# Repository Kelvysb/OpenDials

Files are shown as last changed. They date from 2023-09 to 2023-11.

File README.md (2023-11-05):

# OpenDials
Open Dials - Open Source Gamepad 

[Color Roll Test Game](https://github.com/Kelvysb/ColorRoll)

Version video:

https://www.youtube.com/watch?v=tNQyPmjfuhA&t=68s&ab_channel=CiaNCIStudio

V1 3d: models (printables)

https://www.thingiverse.com/thing:6273114

https://skfb.ly/oMzWV

Ingredients:
1 - Arduino Pro micro
7 - push buttons
2 - rotary encoders
2 - leds
1 - 1k resistor
A lot - Wires
4 - M3 - bolts and nuts

Circuit:

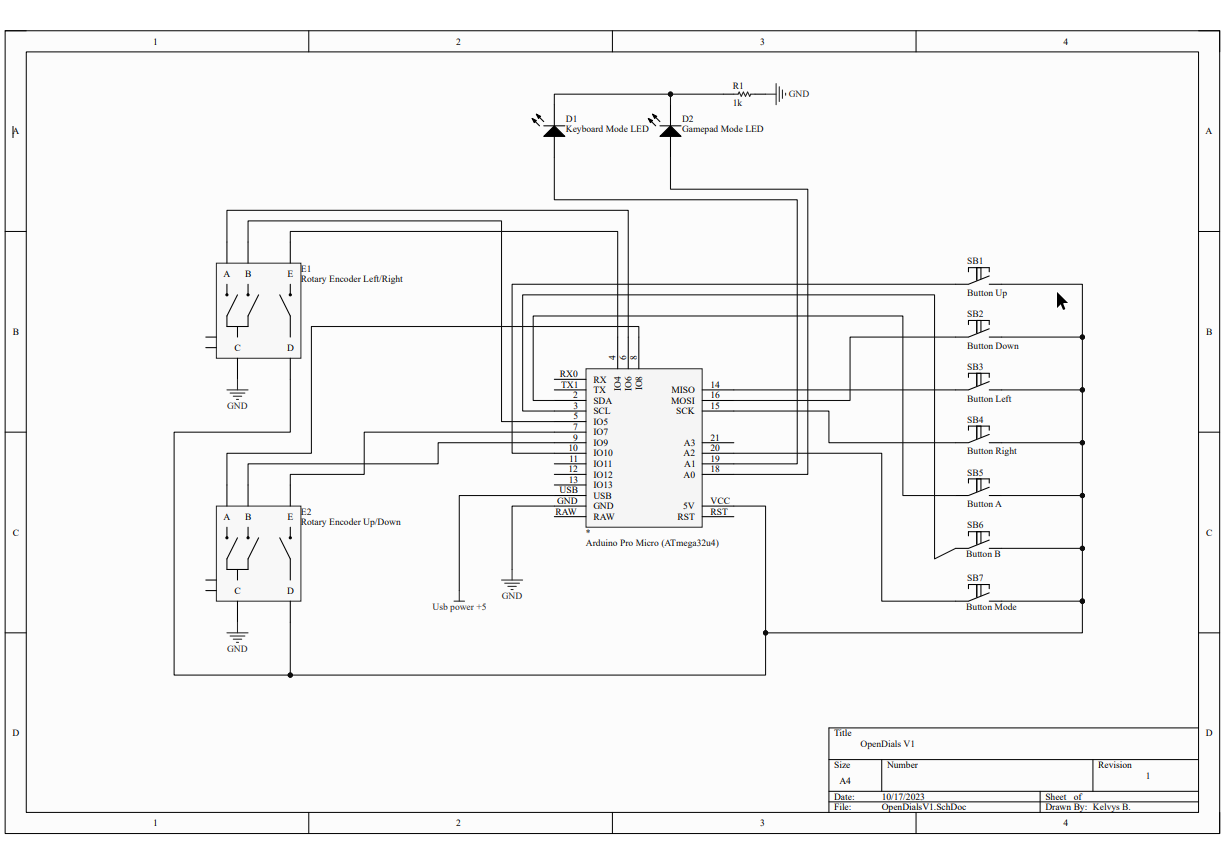
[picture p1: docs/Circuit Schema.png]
circuit


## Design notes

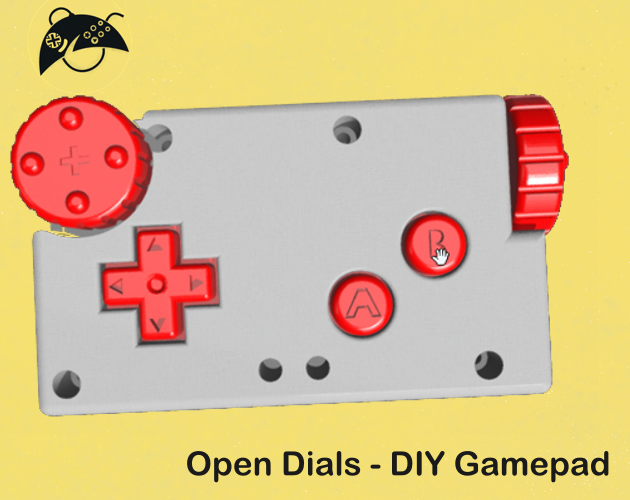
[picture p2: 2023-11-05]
docs/Cover.png

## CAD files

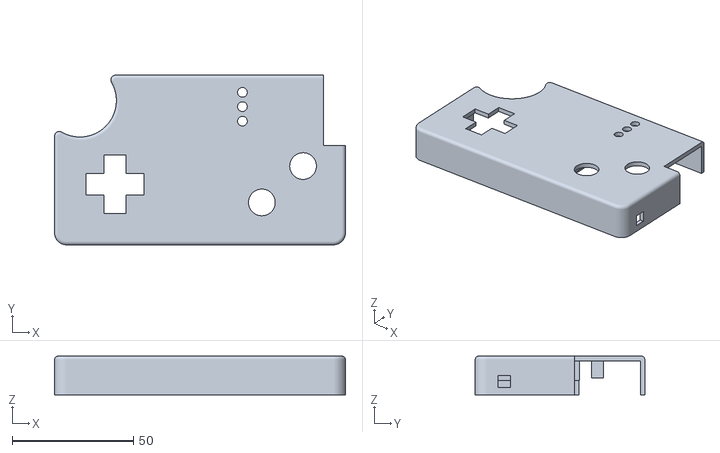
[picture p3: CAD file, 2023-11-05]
Hardware/Printing/V3/OpenDials_v3-Top.stl
120.0 x 70.0 x 16.0

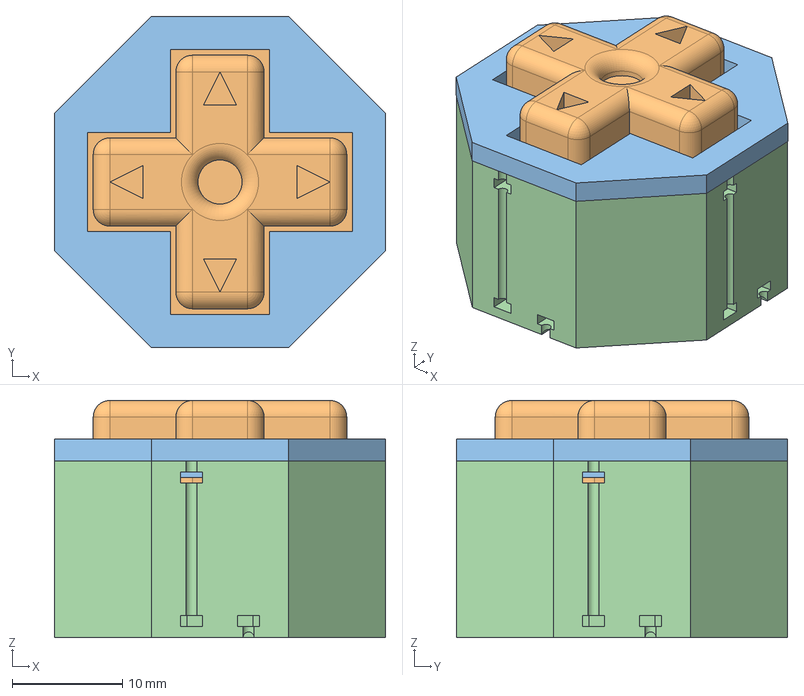
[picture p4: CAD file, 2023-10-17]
Hardware/Source/OpenDials_v2/OpenDials_v2.FCStd
30.0 x 30.0 x 21.5 mm
DPadDisc
DPadButtons
DPadTop
DPadBody

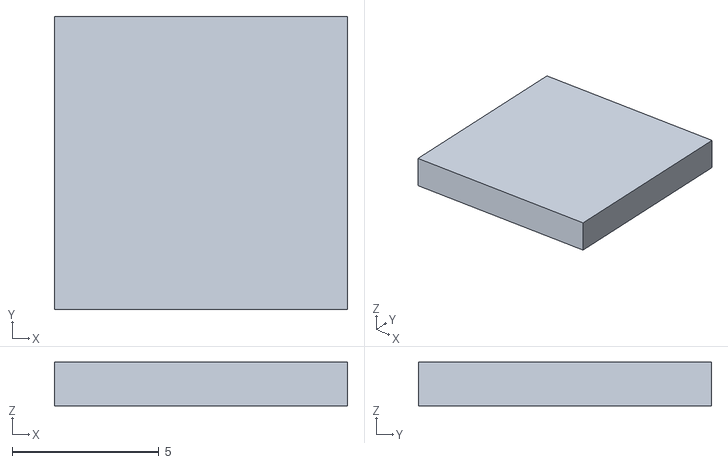
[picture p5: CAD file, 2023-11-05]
Hardware/Printing/V3/OpenDials_v3-ButtonsPlate.stl
10.0 x 10.0 x 1.50

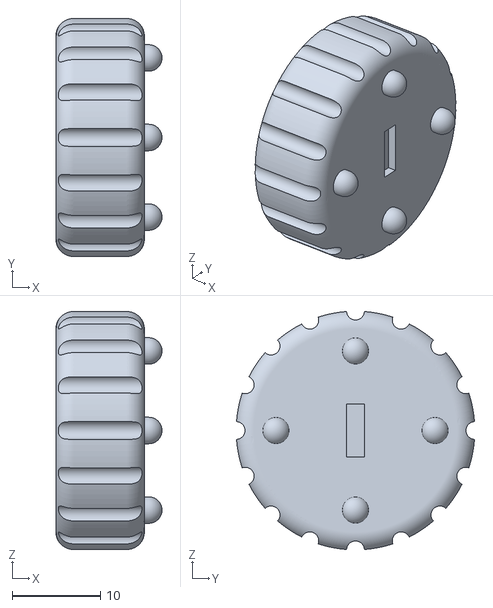
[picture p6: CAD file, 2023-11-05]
Hardware/Printing/V3/OpenDials_v3-DialUD.stl
12.0 x 26.9 x 26.9

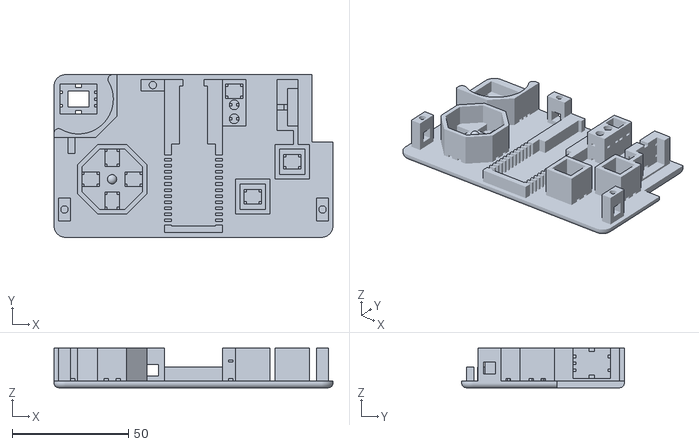
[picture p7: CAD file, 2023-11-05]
Hardware/Printing/V3/OpenDials_v3-Bottom.stl
120.0 x 70.0 x 17.0

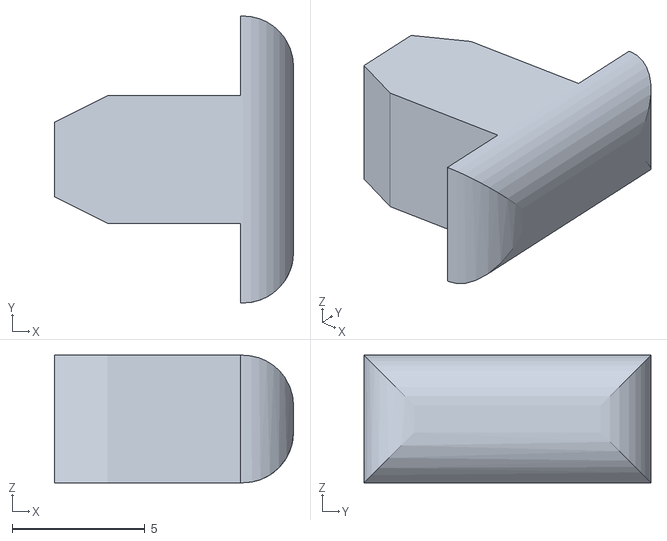
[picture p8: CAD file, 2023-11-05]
Hardware/Printing/V3/OpenDials_v3-ClosingPin.stl
9.00 x 10.8 x 4.80

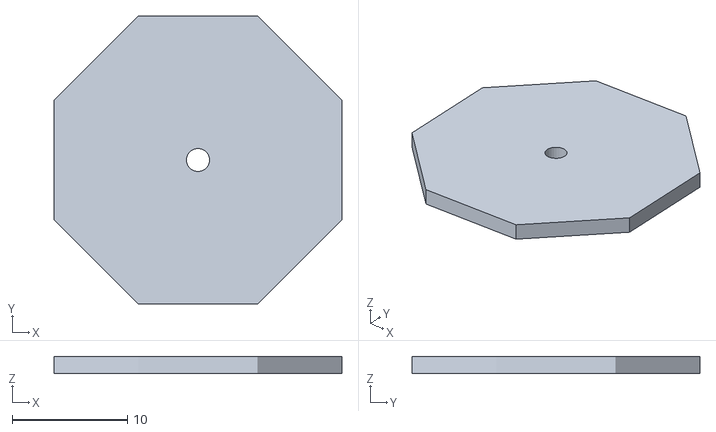
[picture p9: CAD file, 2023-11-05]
Hardware/Printing/V3/OpenDials_v3-DPadDisc.stl
24.9 x 24.9 x 1.50

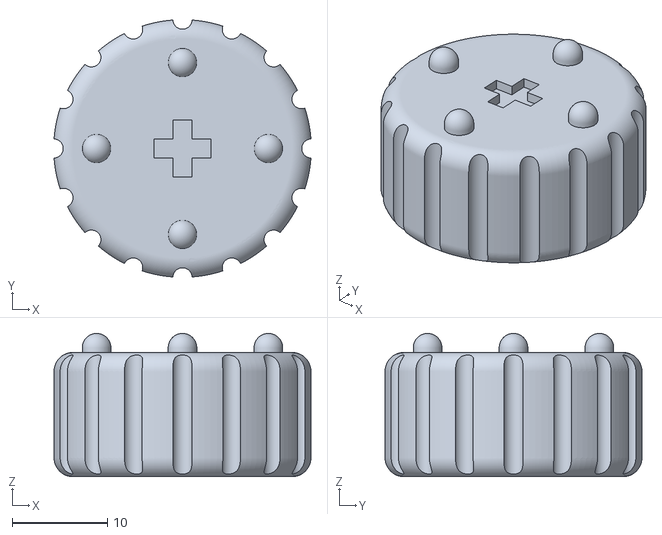
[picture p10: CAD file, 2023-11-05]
Hardware/Printing/V3/OpenDials_v3-RLDial.stl
26.9 x 26.9 x 15.0

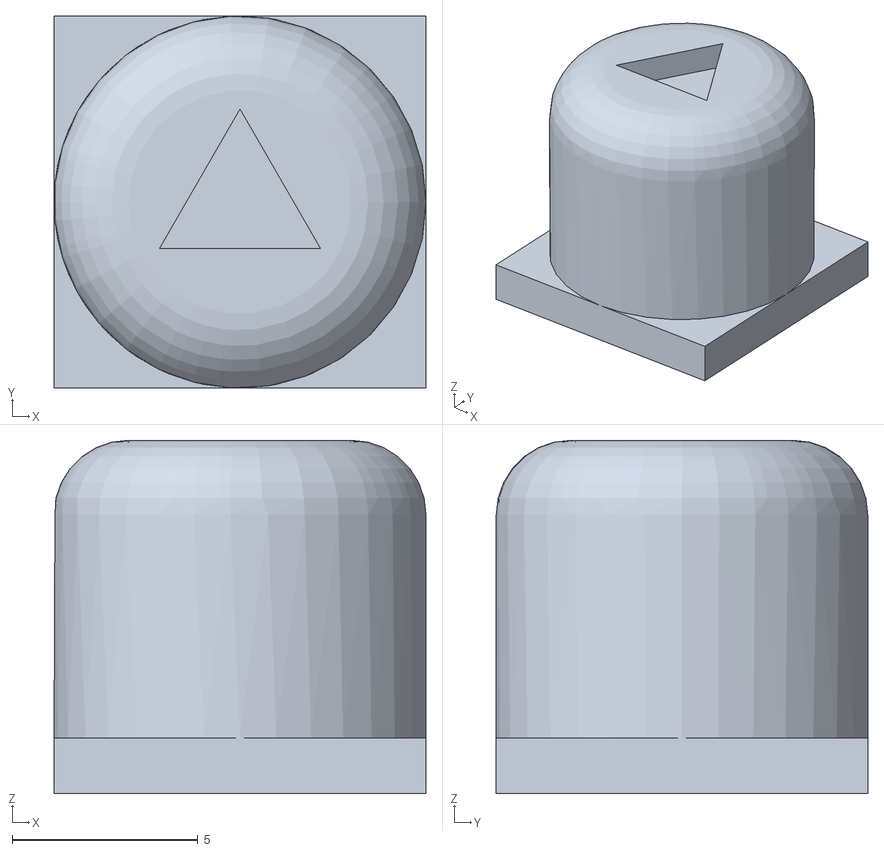
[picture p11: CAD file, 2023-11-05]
Hardware/Printing/V3/OpenDials_v3-ButtonA.stl
10.0 x 10.0 x 9.50

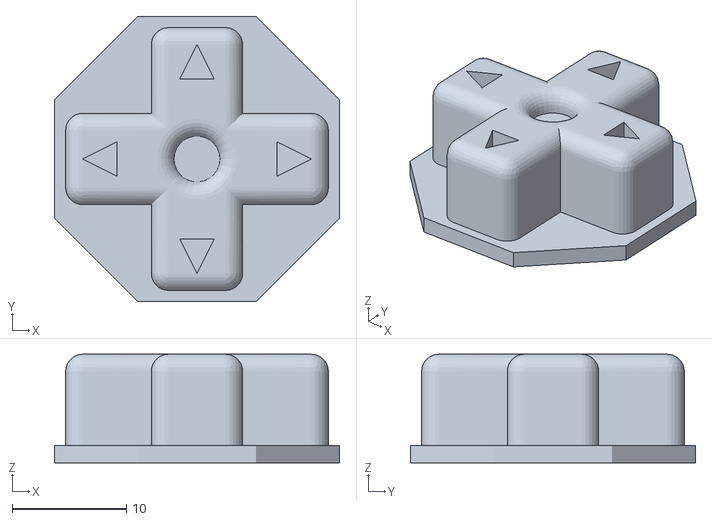
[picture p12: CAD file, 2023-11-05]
Hardware/Printing/V3/OpenDials_v3-DPadButtons.stl
24.9 x 24.9 x 9.50

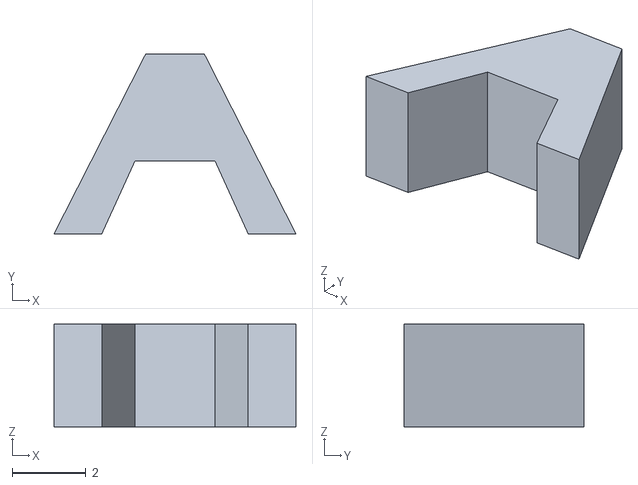
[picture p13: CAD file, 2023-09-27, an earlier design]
Hardware/Printing/V1/OpenDials-ButtonsDetailA.stl
6.58 x 4.89 x 2.80

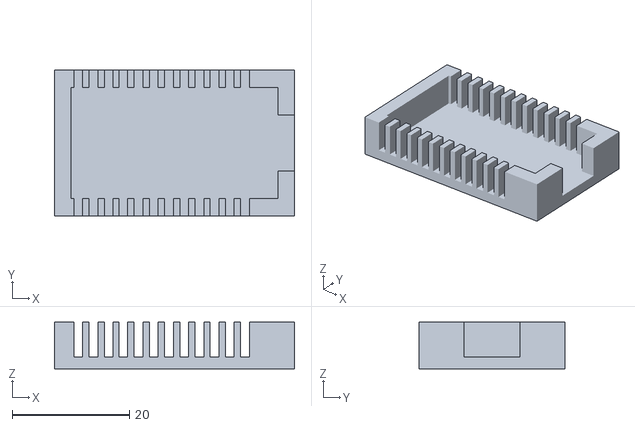
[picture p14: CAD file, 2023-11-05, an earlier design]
Hardware/Printing/V2/ArduinoSlot/ArduinoSlotBody.stl
41.0 x 25.0 x 8.00

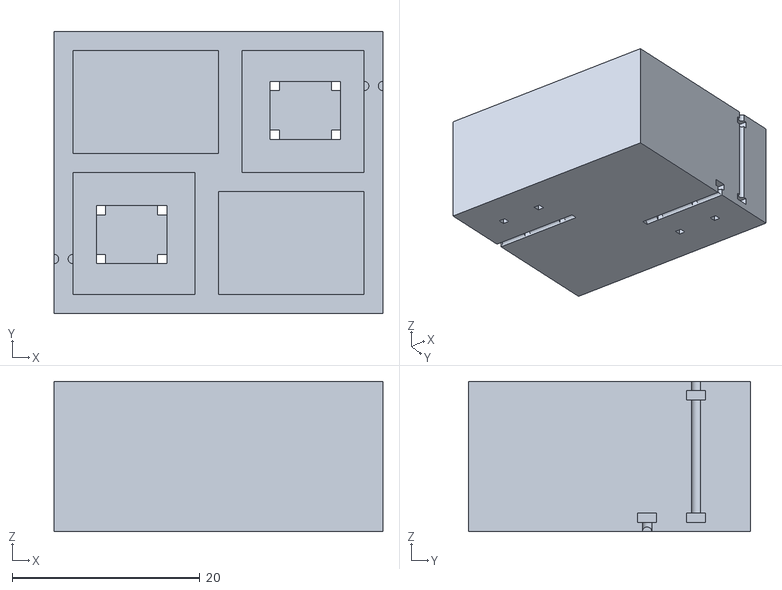
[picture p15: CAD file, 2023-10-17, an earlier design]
Hardware/Printing/V2/Buttons/OpenDials_v2-ButtonsBody.stl
35.0 x 30.0 x 16.0

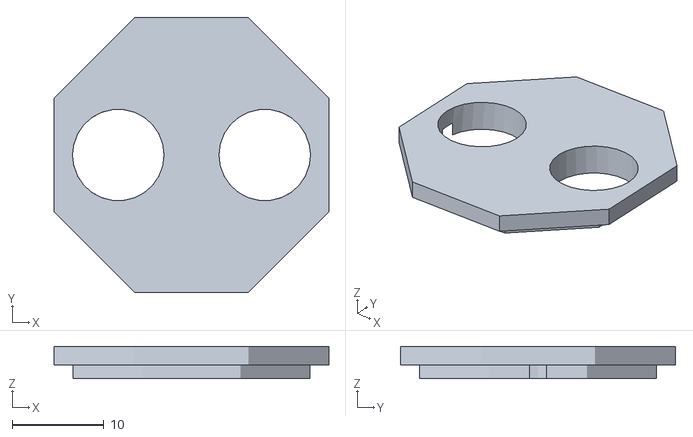
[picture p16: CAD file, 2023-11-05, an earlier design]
Hardware/Printing/V2/ButtonsOct/ButtonsOctTop.stl
30.0 x 30.0 x 3.50

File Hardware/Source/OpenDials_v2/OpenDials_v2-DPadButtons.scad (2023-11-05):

// CSG file generated from FreeCAD 0.21.1
group() {
 group(){
polyhedron ( points = [[3.500000,0.000000,21.500000],[-2.500000,-2.500000,21.500000],[-10.000000,-2.500000,21.500000],[-10.000000,0.000000,21.500000],[-10.000000,2.500000,21.500000],[-2.500000,2.500000,21.500000],[-2.500000,10.000000,21.500000],[0.000000,10.000000,21.500000],[2.500000,10.000000,21.500000],[2.500000,2.500000,21.500000],[10.000000,2.500000,21.500000],[10.000000,0.000000,21.500000],[10.000000,-2.500000,21.500000],[2.500000,-2.500000,21.500000],[2.500000,-10.000000,21.500000],[-0.000000,-10.000000,21.500000],[-2.500000,-10.000000,21.500000],[7.000000,-1.500000,21.500000],[7.000000,1.500000,21.500000],[-1.500000,-7.000000,21.500000],[1.500000,-7.000000,21.500000],[1.500000,7.000000,21.500000],[-1.500000,7.000000,21.500000],[-7.000000,1.500000,21.500000],[-7.000000,-1.500000,21.500000],[2.000000,0.000000,20.000000],[-4.000000,-4.000000,20.000000],[-10.000000,-4.000000,20.000000],[-11.500000,-2.500000,20.000000],[-11.500000,2.500000,20.000000],[-10.000000,4.000000,20.000000],[-4.000000,4.000000,20.000000],[-4.000000,10.000000,20.000000],[-2.500000,11.500000,20.000000],[2.500000,11.500000,20.000000],[4.000000,10.000000,20.000000],[4.000000,4.000000,20.000000],[10.000000,4.000000,20.000000],[11.500000,2.500000,20.000000],[11.500000,-2.500000,20.000000],[10.000000,-4.000000,20.000000],[4.000000,-4.000000,20.000000],[4.000000,-10.000000,20.000000],[2.500000,-11.500000,20.000000],[-2.500000,-11.500000,20.000000],[-4.000000,-10.000000,20.000000],[7.000000,-1.500000,19.500000],[10.000000,0.000000,19.500000],[7.000000,1.500000,19.500000],[-1.500000,-7.000000,19.500000],[-0.000000,-10.000000,19.500000],[1.500000,-7.000000,19.500000],[1.500000,7.000000,19.500000],[0.000000,10.000000,19.500000],[-1.500000,7.000000,19.500000],[-7.000000,1.500000,19.500000],[-10.000000,0.000000,19.500000],[-7.000000,-1.500000,19.500000],[2.000000,0.000000,19.500000],[-4.000000,-4.000000,13.500000],[-10.000000,-4.000000,13.500000],[-11.500000,-2.500000,13.500000],[-11.500000,2.500000,13.500000],[-4.000000,4.000000,13.500000],[-10.000000,4.000000,13.500000],[-4.000000,10.000000,13.500000],[-2.500000,11.500000,13.500000],[2.500000,11.500000,13.500000],[4.000000,4.000000,13.500000],[4.000000,10.000000,13.500000],[10.000000,4.000000,13.500000],[11.500000,2.500000,13.500000],[11.500000,-2.500000,13.500000],[4.000000,-4.000000,13.500000],[10.000000,-4.000000,13.500000],[4.000000,-10.000000,13.500000],[2.500000,-11.500000,13.500000],[-2.500000,-11.500000,13.500000],[-4.000000,-10.000000,13.500000],[5.166226,-12.472374,13.500000],[12.472374,-5.166226,13.500000],[12.472374,5.166226,13.500000],[5.166226,12.472374,13.500000],[-5.166226,12.472374,13.500000],[-12.472374,5.166226,13.500000],[-12.472374,-5.166226,13.500000],[-5.166226,-12.472374,13.500000],[5.166226,-12.472374,12.000000],[12.472374,-5.166226,12.000000],[12.472374,5.166226,12.000000],[5.166226,12.472374,12.000000],[-5.166226,12.472374,12.000000],[-12.472374,5.166226,12.000000],[-12.472374,-5.166226,12.000000],[-5.166226,-12.472374,12.000000],[3.197409,1.423578,21.500000],[2.341957,2.601007,21.500000],[1.081560,3.328698,21.500000],[-0.365850,3.480827,21.500000],[-1.750000,3.031089,21.500000],[-2.831559,2.057248,21.500000],[-3.423517,0.727691,21.500000],[-3.423517,-0.727691,21.500000],[-2.831559,-2.057248,21.500000],[-1.750000,-3.031089,21.500000],[-0.365850,-3.480827,21.500000],[1.081560,-3.328698,21.500000],[2.341957,-2.601007,21.500000],[3.197409,-1.423578,21.500000],[-3.750000,-2.500000,21.500000],[-5.000000,-2.500000,21.500000],[-6.250000,-2.500000,21.500000],[-7.500000,-2.500000,21.500000],[-8.750000,-2.500000,21.500000],[-10.000000,-1.666667,21.500000],[-10.000000,-0.833333,21.500000],[-10.000000,0.833333,21.500000],[-10.000000,1.666667,21.500000],[-8.750000,2.500000,21.500000],[-7.500000,2.500000,21.500000],[-6.250000,2.500000,21.500000],[-5.000000,2.500000,21.500000],[-3.750000,2.500000,21.500000],[-2.500000,3.750000,21.500000],[-2.500000,5.000000,21.500000],[-2.500000,6.250000,21.500000],[-2.500000,7.500000,21.500000],[-2.500000,8.750000,21.500000],[-1.666667,10.000000,21.500000],[-0.833333,10.000000,21.500000],[0.833333,10.000000,21.500000],[1.666667,10.000000,21.500000],[2.500000,8.750000,21.500000],[2.500000,7.500000,21.500000],[2.500000,6.250000,21.500000],[2.500000,5.000000,21.500000],[2.500000,3.750000,21.500000],[3.750000,2.500000,21.500000],[5.000000,2.500000,21.500000],[6.250000,2.500000,21.500000],[7.500000,2.500000,21.500000],[8.750000,2.500000,21.500000],[10.000000,1.666667,21.500000],[10.000000,0.833333,21.500000],[10.000000,-0.833333,21.500000],[10.000000,-1.666667,21.500000],[8.750000,-2.500000,21.500000],[7.500000,-2.500000,21.500000],[6.250000,-2.500000,21.500000],[5.000000,-2.500000,21.500000],[3.750000,-2.500000,21.500000],[2.500000,-3.750000,21.500000],[2.500000,-5.000000,21.500000],[2.500000,-6.250000,21.500000],[2.500000,-7.500000,21.500000],[2.500000,-8.750000,21.500000],[1.666667,-10.000000,21.500000],[0.833333,-10.000000,21.500000],[-0.833333,-10.000000,21.500000],[-1.666667,-10.000000,21.500000],[-2.500000,-8.750000,21.500000],[-2.500000,-7.500000,21.500000],[-2.500000,-6.250000,21.500000],[-2.500000,-5.000000,21.500000],[-2.500000,-3.750000,21.500000],[7.750000,-1.125000,21.500000],[8.500000,-0.750000,21.500000],[9.250000,-0.375000,21.500000],[9.250000,0.375000,21.500000],[8.500000,0.750000,21.500000],[7.750000,1.125000,21.500000],[7.000000,0.750000,21.500000],[7.000000,0.000000,21.500000],[7.000000,-0.750000,21.500000],[-1.125000,-7.750000,21.500000],[-0.750000,-8.500000,21.500000],[-0.375000,-9.250000,21.500000],[0.375000,-9.250000,21.500000],[0.750000,-8.500000,21.500000],[1.125000,-7.750000,21.500000],[0.750000,-7.000000,21.500000],[-0.000000,-7.000000,21.500000],[-0.750000,-7.000000,21.500000],[1.125000,7.750000,21.500000],[0.750000,8.500000,21.500000],[0.375000,9.250000,21.500000],[-0.375000,9.250000,21.500000],[-0.750000,8.500000,21.500000],[-1.125000,7.750000,21.500000],[-0.750000,7.000000,21.500000],[0.000000,7.000000,21.500000],[0.750000,7.000000,21.500000],[-7.750000,1.125000,21.500000],[-8.500000,0.750000,21.500000],[-9.250000,0.375000,21.500000],[-9.250000,-0.375000,21.500000],[-8.500000,-0.750000,21.500000],[-7.750000,-1.125000,21.500000],[-7.000000,-0.750000,21.500000],[-7.000000,0.000000,21.500000],[-7.000000,0.750000,21.500000],[2.750000,0.000000,21.299038],[2.200962,0.000000,20.750000],[1.532089,1.285575,20.000000],[0.347296,1.969615,20.000000],[-1.000000,1.732051,20.000000],[-1.879385,0.684040,20.000000],[-1.879385,-0.684040,20.000000],[-1.000000,-1.732051,20.000000],[0.347296,-1.969615,20.000000],[1.532089,-1.285575,20.000000],[-3.734545,-3.734545,20.851995],[-3.163246,-3.163246,21.345402],[-10.000000,-3.250000,21.299038],[-10.000000,-3.799038,20.750000],[-5.200000,-4.000000,20.000000],[-6.400000,-4.000000,20.000000],[-7.600000,-4.000000,20.000000],[-8.800000,-4.000000,20.000000],[-10.750000,-2.500000,21.299038],[-11.299038,-2.500000,20.750000],[-10.750000,2.500000,21.299038],[-11.299038,2.500000,20.750000],[-11.500000,-1.500000,20.000000],[-11.500000,-0.500000,20.000000],[-11.500000,0.500000,20.000000],[-11.500000,1.500000,20.000000],[-10.000000,3.250000,21.299038],[-10.000000,3.799038,20.750000],[-3.734545,3.734545,20.851995],[-3.163246,3.163246,21.345402],[-8.800000,4.000000,20.000000],[-7.600000,4.000000,20.000000],[-6.400000,4.000000,20.000000],[-5.200000,4.000000,20.000000],[-3.250000,10.000000,21.299038],[-3.799038,10.000000,20.750000],[-4.000000,5.200000,20.000000],[-4.000000,6.400000,20.000000],[-4.000000,7.600000,20.000000],[-4.000000,8.800000,20.000000],[-2.500000,10.750000,21.299038],[-2.500000,11.299038,20.750000],[2.500000,10.750000,21.299038],[2.500000,11.299038,20.750000],[-1.500000,11.500000,20.000000],[-0.500000,11.500000,20.000000],[0.500000,11.500000,20.000000],[1.500000,11.500000,20.000000],[3.250000,10.000000,21.299038],[3.799038,10.000000,20.750000],[3.734545,3.734545,20.851995],[3.163246,3.163246,21.345402],[4.000000,8.800000,20.000000],[4.000000,7.600000,20.000000],[4.000000,6.400000,20.000000],[4.000000,5.200000,20.000000],[10.000000,3.250000,21.299038],[10.000000,3.799038,20.750000],[5.200000,4.000000,20.000000],[6.400000,4.000000,20.000000],[7.600000,4.000000,20.000000],[8.800000,4.000000,20.000000],[10.750000,2.500000,21.299038],[11.299038,2.500000,20.750000],[10.750000,-2.500000,21.299038],[11.299038,-2.500000,20.750000],[11.500000,1.500000,20.000000],[11.500000,0.500000,20.000000],[11.500000,-0.500000,20.000000],[11.500000,-1.500000,20.000000],[10.000000,-3.250000,21.299038],[10.000000,-3.799038,20.750000],[3.734545,-3.734545,20.851995],[3.163246,-3.163246,21.345402],[8.800000,-4.000000,20.000000],[7.600000,-4.000000,20.000000],[6.400000,-4.000000,20.000000],[5.200000,-4.000000,20.000000],[3.250000,-10.000000,21.299038],[3.799038,-10.000000,20.750000],[4.000000,-5.200000,20.000000],[4.000000,-6.400000,20.000000],[4.000000,-7.600000,20.000000],[4.000000,
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

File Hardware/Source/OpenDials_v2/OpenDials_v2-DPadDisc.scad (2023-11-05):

// CSG file generated from FreeCAD 0.21.1
group() {
 group(){
polyhedron ( points = [[12.472374,-5.166226,9.000000],[12.472374,-5.166226,10.500000],[12.472374,5.166226,9.000000],[12.472374,5.166226,10.500000],[5.166226,-12.472374,9.000000],[5.166226,-12.472374,10.500000],[5.166226,12.472374,9.000000],[5.166226,12.472374,10.500000],[-5.166226,-12.472374,9.000000],[-5.166226,12.472374,9.000000],[-12.472374,-5.166226,9.000000],[-12.472374,5.166226,9.000000],[1.000000,0.000000,9.000000],[-5.166226,-12.472374,10.500000],[-5.166226,12.472374,10.500000],[-12.472374,-5.166226,10.500000],[-12.472374,5.166226,10.500000],[1.000000,0.000000,10.500000],[12.472374,-5.166226,9.750000],[12.472374,5.166226,9.750000],[12.472374,-2.583113,9.000000],[12.472374,-0.000000,9.000000],[12.472374,2.583113,9.000000],[12.472374,-2.583113,10.500000],[12.472374,-0.000000,10.500000],[12.472374,2.583113,10.500000],[5.166226,-12.472374,9.750000],[6.992763,-10.645837,9.000000],[8.819300,-8.819300,9.000000],[10.645837,-6.992763,9.000000],[6.992763,-10.645837,10.500000],[8.819300,-8.819300,10.500000],[10.645837,-6.992763,10.500000],[5.166226,12.472374,9.750000],[10.645837,6.992763,9.000000],[8.819300,8.819300,9.000000],[6.992763,10.645837,9.000000],[10.645837,6.992763,10.500000],[8.819300,8.819300,10.500000],[6.992763,10.645837,10.500000],[-2.583113,-12.472374,9.000000],[0.000000,-12.472374,9.000000],[2.583113,-12.472374,9.000000],[2.583113,12.472374,9.000000],[0.000000,12.472374,9.000000],[-2.583113,12.472374,9.000000],[-10.645837,-6.992763,9.000000],[-8.819300,-8.819300,9.000000],[-6.992763,-10.645837,9.000000],[-6.992763,10.645837,9.000000],[-8.819300,8.819300,9.000000],[-10.645837,6.992763,9.000000],[-12.472374,2.583113,9.000000],[-12.472374,-0.000000,9.000000],[-12.472374,-2.583113,9.000000],[0.000000,1.000000,9.000000],[-1.000000,0.000000,9.000000],[-0.000000,-1.000000,9.000000],[-2.583113,-12.472374,10.500000],[0.000000,-12.472374,10.500000],[2.583113,-12.472374,10.500000],[2.583113,12.472374,10.500000],[0.000000,12.472374,10.500000],[-2.583113,12.472374,10.500000],[-10.645837,-6.992763,10.500000],[-8.819300,-8.819300,10.500000],[-6.992763,-10.645837,10.500000],[-6.992763,10.645837,10.500000],[-8.819300,8.819300,10.500000],[-10.645837,6.992763,10.500000],[-12.472374,2.583113,10.500000],[-12.472374,-0.000000,10.500000],[-12.472374,-2.583113,10.500000],[0.000000,1.000000,10.500000],[-1.000000,0.000000,10.500000],[-0.000000,-1.000000,10.500000],[-5.166226,-12.472374,9.750000],[-5.166226,12.472374,9.750000],[-12.472374,-5.166226,9.750000],[-12.472374,5.166226,9.750000],[1.000000,0.000000,9.750000],[12.472374,3.428589,10.492579],[12.472374,1.142863,10.492579],[12.472374,-1.142863,10.492579],[12.472374,-3.428590,10.492579],[11.243679,-6.394921,10.492579],[9.627426,-8.011174,10.492579],[8.011174,-9.627426,10.492579],[6.394921,-11.243679,10.492579],[6.394921,11.243679,10.492579],[8.011174,9.627426,10.492579],[9.627426,8.011174,10.492579],[11.243679,6.394921,10.492579],[1.618650,7.692821,9.000000],[8.280828,3.846411,9.000000],[-11.705707,-0.000000,9.000000],[1.618650,-7.692821,9.000000],[8.280828,-3.846411,9.000000],[-5.043528,11.539231,9.000000],[-5.043528,-11.539231,9.000000],[1.618650,-0.000000,9.000000],[-5.043528,-3.846411,9.000000],[-5.043528,3.846411,9.000000],[-11.705707,3.846411,9.000000],[-11.705707,-3.846411,9.000000],[-1.712439,9.616026,9.000000],[1.618650,11.539231,9.000000],[4.949739,9.616026,9.000000],[4.949739,5.769616,9.000000],[8.280828,7.692821,9.000000],[11.611918,5.769616,9.000000],[11.611918,1.923205,9.000000],[-1.712439,-9.616026,9.000000],[1.618650,-11.539231,9.000000],[4.949739,-5.769616,9.000000],[4.949739,-9.616026,9.000000],[8.280828,-7.692821,9.000000],[11.611918,-1.923205,9.000000],[11.611918,-5.769616,9.000000],[8.280828,-0.000000,9.000000],[4.949739,-1.923205,9.000000],[1.618650,-3.846411,9.000000],[4.949739,1.923205,9.000000],[1.618650,3.846411,9.000000],[-1.712439,-5.769616,9.000000],[-5.043528,-7.692821,9.000000],[-8.374618,-5.769616,9.000000],[-8.374618,-1.923205,9.000000],[-1.712439,5.769616,9.000000],[-5.043528,7.692821,9.000000],[-8.374618,1.923205,9.000000],[-8.374618,5.769616,9.000000],[-5.043528,-0.000000,9.000000],[-1.712439,1.923205,9.000000],[-1.712439,-1.923205,9.000000],[-11.705707,5.769616,9.000000],[-11.705707,1.923205,9.000000],[-11.705707,-1.923205,9.000000],[-11.705707,-5.769616,9.000000],[-3.377984,10.577629,9.000000],[-1.712439,11.539231,9.000000],[-0.046894,10.577629,9.000000],[-0.046894,8.654424,9.000000],[1.618650,9.616026,9.000000],[3.284195,8.654424,9.000000],[3.284195,6.731218,9.000000],[4.949739,7.692821,9.000000],[6.615284,10.577629,9.000000],[6.615284,8.654424,9.000000],[6.615284,6.731218,9.000000],[6.615284,4.808013,9.000000],[8.280828,5.769616,9.000000],[9.946373,4.808013,9.000000],[9.946373,2.884808,9.000000],[11.611918,3.846411,9.000000],[9.946373,6.731218,9.000000],[4.949739,11.539231,9.000000],[3.284195,10.577629,9.000000],[-3.377984,-10.577629,9.000000],[-1.712439,-11.539231,9.000000],[-0.046894,-8.654424,9.000000],[-0.046894,-10.577629,9.000000],[1.618650,-9.616026,9.000000],[3.284195,-6.731218,9.000000],[3.284195,-8.654424,9.000000],[4.949739,-7.692821,9.000000],[6.615284,-4.808013,9.000000],[6.615284,-6.731218,9.000000],[8.280828,-5.769616,9.000000],[6.615284,-8.654424,9.000000],[6.615284,-10.577629,9.000000],[9.946373,-2.884808,9.000000],[9.946373,-4.808013,9.000000],[11.611918,-3.846411,9.000000],[9.946373,-6.731218,9.000000],[4.949739,-11.539231,9.000000],[3.284195,-10.577629,9.000000],[11.611918,-0.000000,9.000000],[9.946373,-0.961603,9.000000],[8.280828,-1.923205,9.000000],[9.946373,0.961603,9.000000],[8.280828,1.923205,9.000000],[6.615284,-2.884808,9.000000],[4.949739,-3.846411,9.000000],[3.284195,-4.808013,9.000000],[1.618650,-5.769616,9.000000],[3.284195,-2.884808,9.000000],[3.284195,-0.961603,9.000000],[1.618650,-1.923205,9.000000],[6.615284,2.884808,9.000000],[4.949739,3.846411,9.000000],[3.284195,0.961603,9.000000],[3.284195,2.884808,9.000000],[1.618650,1.923205,9.000000],[3.284195,4.808013,9.000000],[1.618650,5.769616,9.000000],[4.949739,-0.000000,9.000000],[6.615284,0.961603,9.000000],[6.615284,-0.961603,9.000000],[-0.046894,-6.731218,9.000000],[-1.712439,-7.692821,9.000000],[-3.377984,-8.654424,9.000000],[-5.043528,-9.616026,9.000000],[-3.377984,-6.731218,9.000000],[-3.377984,-4.808013,9.000000],[-5.043528,-5.769616,9.000000],[-6.709073,-10.577629,9.000000],[-6.709073,-4.808013,9.000000],[-6.709073,-2.884808,9.000000],[-8.374618,-3.846411,9.000000],[-10.040162,-6.731218,9.000000],[-10.040162,-4.808013,9.000000],[-10.040162,-2.884808,9.000000],[-10.040162,-0.961603,9.000000],[-8.374618,-7.692821,9.000000],[-6.709073,-6.731218,9.000000],[-6.709073,-8.654424,9.000000],[-0.046894,6.731218,9.000000],[-1.712439,7.692821,9.000000],[-3.377984,4.808013,9.000000],[-3.377984,6.731218,9.000000],[-5.043528,5.769616,9.000000],[-3.377984,8.654424,9.000000],[-5.043528,9.616026,9.000000],[-6.709073,2.884808,9.000000],[-6.709073,4.808013,9.000000],[-8.374618,3.846411,9.000000],[-10.040162,0.961603,9.000000],[-10.040162,2.884808,9.000000],[-10.040162,4.808013,9.000000],[-10.040162,6.731218,9.000000],[-6.709073,10.577629,9.000000],[-8.374618,7.692821,9.000000],[-6.709073,8.654424,9.000000],[-6.709073,6.731218,9.000000],[-8.374618,-0.000000,9.000000],[-6.709073,0.961603,9.000000],[-5.043528,1.923205,9.000000],[-6.709073,-0.961603,9.000000],[-5.043528,-1.923205,9.000000],[-3.377984,2.884808,9.000000],[-1.712439,3.846411,9.000000],[-0.046894,4.808013,9.000000],[-0.046894,2.884808,9.000000],[-0.046894,0.961603,9.000000],[-3.377984,-2.884808,9.000000],[-1.712439,-3.846411,9.000000],[-0.046894,-0.961603,9.000000],[-0.046894,-2.884808,9.000000],[-0.046894,-4.808013,9.000000],[-1.712439,-0.000000,9.000000],[-3.377984,-0.961603,9.000000],[-3.377984,0.961603,9.000000],[1.618650,7.692821,10.500000],[8.280828,3.846411,10.500000],[-11.705707,-0.000000,10.500000],[1.618650,-7.692821,10.500000],[8.280828,-3.846411,10.500000],[-5.043528,11.539231,10.500000],[-5.043528,-11.539231,10.500000],[1.618650,-0.000000,10.500000],[-5.043528,-3.846411,10.500000],[-5.043528,3.846411,10.500000],[-11.705707,3.846411,10.500000],[-11.705707,-3.846411,10.500000],[-1.712439,9.616026,10.500000],[1.618650,11.539231,10.500000],[4.949739,9.616026,10.500000],[4.949739,5.769616,10.500000],[8.280828,7.692821,10.500000],[11.611918,5.769616,10.500000],[11.611918,1.923205,10.500000],[-1.712439,-9.616026,10.500000],[1.618650,-11.539231,10.500000],[4.949739,-5.769616,10.500000],[4.949739,-9.616026,10.500000],[8.280828,-7.692821,10.500000],[11.611918,-1.923205,10.500000],[11.611918,-5.769616,10.500000],[8.280828,-0.000000,10.500000],[4.949739,-1.923205,10.500000],[1.618650,-3.846411,10.500000],[4.949739,1.923205,10.500000],[1.618650,3.846411,10.500000],[-1.712439,-5.769616,10.500000],[-5.043528,-7.692821,10.500000],[-8.374618,-5.769616,10.500000],[-8.374618,-1.923205,10.500000],[-1.712439,5.769616,10.500000],[-5.043528,7.692821,10.500000],[-8.374
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

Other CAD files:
Hardware/Printing/V3/OpenDials_v3-ButtonB.stl
Hardware/Printing/V2/Dial/Dial-Body.stl
Hardware/Printing/V2/DPad/CE3_OpenDials_v2-DPad-Body.3mf
Hardware/Printing/V2/Frame/Frame.stl
Hardware/Source/OpenDials_v2/OpenDials_v2-DialButton.scad
Hardware/Source/OpenDials_v2/OpenDials_v2-DPadBody.scad
Hardware/Printing/V1/CE3_OpenDials-Buttons.3mf
Hardware/Printing/V1/CE3_OpenDials-ButtonsDetails.3mf
Hardware/Printing/V1/CE3_OpenDials_Body.3mf
Hardware/Printing/V1/OpenDials-Base.stl
Hardware/Printing/V1/OpenDials-Buttons.stl
Hardware/Printing/V1/OpenDials-ButtonsDetailB.stl
Hardware/Printing/V1/OpenDials-Core.stl
Hardware/Printing/V1/OpenDials-DialRL.stl
Hardware/Printing/V1/OpenDials-DialUD.stl
Hardware/Printing/V1/OpenDials-Directional.stl
Hardware/Printing/V1/OpenDials-ModeButton.stl
Hardware/Printing/V1/OpenDials-Top.stl
Hardware/Printing/V2/ArduinoSlot/ArduinoSlotTop.stl
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

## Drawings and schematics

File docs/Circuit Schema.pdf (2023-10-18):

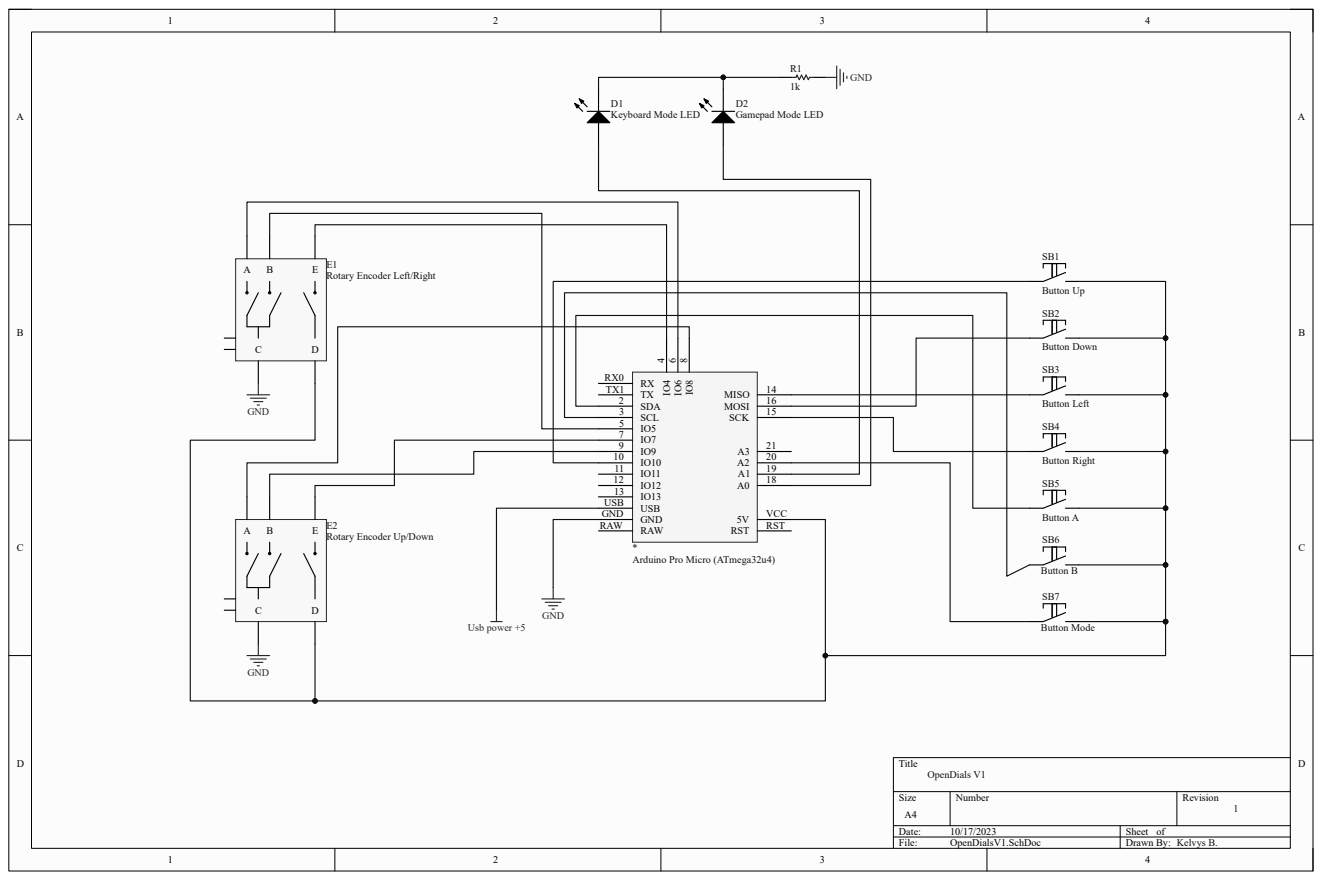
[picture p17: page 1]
Title; Size; Number; Revision; Date:; Sheet of; File:; OpenDialsV1.SchDoc; Drawn By:; Button Up; Button Down; Button Left; Button Right; Button A; Button B; Button Mode; E1 Rotary Encoder Left/Right; Rotary Encoder Up/Down; RST; RST 5V; VCC; SCK; 15 MOSI; 16 MISO; 14 IO⁸; RX RX0 TX TX1 SDA 2 SCL 3 IO5 5 IO7 7 IO9 9 IO10 10 IO11 11 IO12 12 IO13 13 USB USB GND GND RAW RAW; Usb power +5; GND; OpenDials V1; Kelvys B.

Keyboard Mode LED

Gamepad Mode LED

Arduino Pro Micro (ATmega32u4)

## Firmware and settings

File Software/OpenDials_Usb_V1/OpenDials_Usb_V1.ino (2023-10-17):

/*
Open Dials Gamepad - V1.0
USB version
Arduino pro micro pinout.
*/

#include "NewEncoder.h"
#include "HID-Project.h"
#include <EEPROM.h>

NewEncoder firstEncoder;
NewEncoder secondEncoder;

const int button_up_pin = 10;
const int button_down_pin = 16;
const int button_left_pin = 14;
const int button_right_pin = 15;

const int button_a_pin = 2;
const int button_b_pin = 3;


const int encoder1_a_pin = 6;
const int encoder1_b_pin = 5;
const int button_start_pin = 4;

const int encoder2_a_pin = 8;
const int encoder2_b_pin = 9;
const int button_select_pin = 7;

const int led_mode_joypad_pin = A0;
const int led_mode_keyboard_pin = A1;
const int button_mode_pin = A2;

int encoder1_last = 0;
int encoder2_last = 0;
bool button_up_last = false;
bool button_down_last = false;
bool button_left_last = false;
bool button_right_last = false;
bool button_a_last = false;
bool button_b_last = false;
bool button_start_last = false;
bool button_select_last = false;
bool button_mode_last = false;

bool button_l = false;
bool button_r = false;
bool button_x = false;
bool button_y = false;

bool button_l_state = false;
bool button_r_state = false;
bool button_x_state = false;
bool button_y_state = false;

int mode = 0;
int mode_address = 0;

unsigned long delayTime = 0;

void setup()
{
    pinMode(button_up_pin, INPUT_PULLUP);
    pinMode(button_down_pin, INPUT_PULLUP);
    pinMode(button_left_pin, INPUT_PULLUP);
    pinMode(button_right_pin, INPUT_PULLUP);
    pinMode(button_a_pin, INPUT_PULLUP);
    pinMode(button_b_pin, INPUT_PULLUP);
    pinMode(button_start_pin, INPUT_PULLUP);
    pinMode(button_select_pin, INPUT_PULLUP);

    pinMode(button_mode_pin, INPUT_PULLUP);
    pinMode(led_mode_joypad_pin, OUTPUT);
    pinMode(led_mode_keyboard_pin, OUTPUT);

    firstEncoder.begin(encoder1_a_pin, encoder1_b_pin);
    secondEncoder.begin(encoder2_a_pin, encoder2_b_pin);    
    mode = EEPROM.read(mode_address);
    if(mode != 0 && mode != 1)
    {
      mode = 0;
    } 
    SetMode();
}

void loop()
{      
    firstEncoder.Update();
    secondEncoder.Update();
    
    if (millis() - delayTime < 100)
        return;

    delayTime = millis();      
      
    SetEncoder();
    SelectMode();
      
    if(mode == 0){
      digitalWrite(led_mode_joypad_pin, HIGH);
      digitalWrite(led_mode_keyboard_pin, LOW);
      JoypadMode();
    }
    else
    {
      digitalWrite(led_mode_keyboard_pin, HIGH);
      digitalWrite(led_mode_joypad_pin, LOW);
      KeyboardMode();
    }    
}

void JoypadMode()
{
  bool up = digitalRead(button_up_pin) == LOW;
  bool down = digitalRead(button_down_pin) == LOW;
  bool left = digitalRead(button_left_pin) == LOW;
  bool right = digitalRead(button_right_pin) == LOW;

  bool a = digitalRead(button_a_pin) == LOW;
  bool b = digitalRead(button_b_pin) == LOW;

  bool start = digitalRead(button_start_pin) == LOW;
  bool select = digitalRead(button_select_pin) == LOW;
  

  if(up)
  {
    Gamepad.press(12);
  }
  else
  {
    Gamepad.release(12);
  }

  if(down)
  {
    Gamepad.press(13);
  }
  else
  {
    Gamepad.release(13);
  }

  if(left)
  {
    Gamepad.press(14);
  }
  else
  {
    Gamepad.release(14);
  }

  if(right)
  {
    Gamepad.press(15);
  }
  else
  {
    Gamepad.release(15);
  }

  if(select)
  {
    Gamepad.press(5);
  }
  else
  {
    Gamepad.release(5);
  }

  if(start)
  {
    Gamepad.press(7);
  }
  else
  {
    Gamepad.release(7);
  }

  if(a)
  {
    Gamepad.press(1);
  }
  else
  {
    Gamepad.release(1);
  }

  if(b)
  {
    Gamepad.press(2);
  }
  else
  {
    Gamepad.release(2);
  }

  if(button_x && !button_x_state)
  {
    Gamepad.press(3);    
    button_x_state = true;
  }
  else
  {
    Gamepad.release(3);
    button_x_state = false;
  }

  if(button_y && !button_y_state)
  {
    Gamepad.press(4);    
    button_y_state = true;
  }
  else
  {
    Gamepad.release(4);
    button_y_state = false;
  }

  if(button_l && !button_l_state)
  {
    Gamepad.press(10);
    button_l_state = true;
  }
  else
  {
    Gamepad.release(10);
    button_l_state = false;
  }

  if(button_r && !button_r_state)
  {
    Gamepad.press(11);
    button_r_state = true;
  }
  else
  {
    Gamepad.release(11);
    button_r_state = false;
  }

  Gamepad.write();
}

void KeyboardMode()
{
  bool up = digitalRead(button_up_pin) == LOW;
  bool down = digitalRead(button_down_pin) == LOW;
  bool left = digitalRead(button_left_pin) == LOW;
  bool right = digitalRead(button_right_pin) == LOW;

  bool a = digitalRead(button_a_pin) == LOW;
  bool b = digitalRead(button_b_pin) == LOW;

  bool start = digitalRead(button_start_pin) == LOW;
  bool select = digitalRead(button_select_pin) == LOW;

  if(up)
  {
    Keyboard.press(KEY_W);
  }
  else
  {
    Keyboard.release(KEY_W);
  }

  if(down)
  {
    Keyboard.press(KEY_S);
  }
  else
  {
    Keyboard.release(KEY_S);
  }

  if(left)
  {
    Keyboard.press(KEY_A);
  }
  else
  {
    Keyboard.release(KEY_A);
  }

  if(right)
  {
    Keyboard.press(KEY_D);
  }
  else
  {
    Keyboard.release(KEY_D);
  }

  if(select)
  {
    Keyboard.press(KEY_ESC);
  }
  else
  {
    Keyboard.release(KEY_ESC );
  }

  if(start)
  {
    Keyboard.press(KEY_ENTER);
  }
  else
  {
    Keyboard.release(KEY_ENTER);
  }

  if(a)
  {
    Keyboard.press(KEY_SPACE);
  }
  else
  {
    Keyboard.release(KEY_SPACE);
  }

  if(b)
  {
    Keyboard.press(KEY_RIGHT_SHIFT);
  }
  else
  {
    Keyboard.release(KEY_RIGHT_SHIFT);
  }

  if(button_x && !button_x_state)
  {
    Keyboard.press(KEY_DOWN); 
    button_x_state = true;
  }
  else
  {
    Keyboard.release(KEY_DOWN);
    button_x_state = false;
  }

  if(button_y && !button_y_state)
  {
    Keyboard.press(KEY_UP);    
    button_y_state = true;
  }
  else
  {
    Keyboard.release(KEY_UP);
    button_y_state = false;
  }

  if(button_l && !button_l_state)
  {
    Keyboard.press(KEY_LEFT);
    button_l_state = true;
  }
  else
  {
    Keyboard.release(KEY_LEFT);
    button_l_state = false;
  }

  if(button_r && !button_r_state)
  {
    Keyboard.press(KEY_RIGHT);
    button_r_state = true;
  }
  else
  {
    Keyboard.release(KEY_RIGHT);
    button_r_state = false;
  }

  Keyboard.send();
}

void SetEncoder()
{  
  int encoder1_value = firstEncoder.GetSteps();
  int encoder2_value = secondEncoder.GetSteps();
  if(encoder1_value != encoder1_last) 
    {
      if(encoder1_value > encoder1_last)
      {
        button_r = true;
      }else 
      {
        button_l = true;
      }
      encoder1_last = encoder1_value;
    }
    else
    {
      button_r = false;
      button_l = false;
    }

    if(encoder2_value != encoder2_last) 
    {
      if(encoder2_value > encoder2_last)
      {
        button_x = true;
      }else 
      {
        button_y = true;
      }
      encoder2_last = encoder2_value;
    }
    else
    {
      button_x = false;
      button_y = false;
    }  
}

void SelectMode()
{
  if(GetButtonState(button_mode_pin) != button_mode_last)
  {
    if(GetButtonState(button_mode_pin))
    {      
      if(mode == 0)
      {
        mode = 1;        
      }else
      {
        mode = 0;        
      }    
      EEPROM.write(mode_address, mode);
      SetMode();
    }
    button_mode_last = GetButtonState(button_mode_pin);
  }
}

void SetMode()
{
  if(mode == 0)
  {
    Keyboard.end();
    Gamepad.begin();
  }else
  {
    Gamepad.end();
    Keyboard.begin();
  }      
}

bool GetButtonState(int button){
  if(digitalRead(button) == HIGH) 
  {
    return false;
  }else
  {
    return true;
  }
}

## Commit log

2023-10-17 Version 1
    [CE3_OpenDials-Buttons.3mf, CE3_OpenDials-ButtonsDetails.3mf, CE3_OpenDials_Body.3mf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]
2023-10-18 finished v1 - started v2
    [OpenDials_v1.FCStd, OpenDials_v2.FCStd]
2023-11-05 Version 3 initial
    [ArduinoSlotBody.stl, ArduinoSlotTop.stl, ButtonSlot.stl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]
